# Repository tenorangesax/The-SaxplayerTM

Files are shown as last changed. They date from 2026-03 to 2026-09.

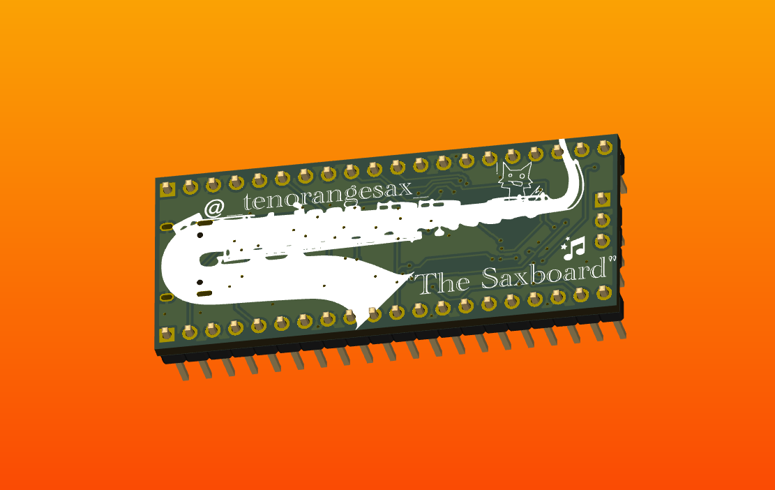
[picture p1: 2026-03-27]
Extra_Materials/Saxboard.png

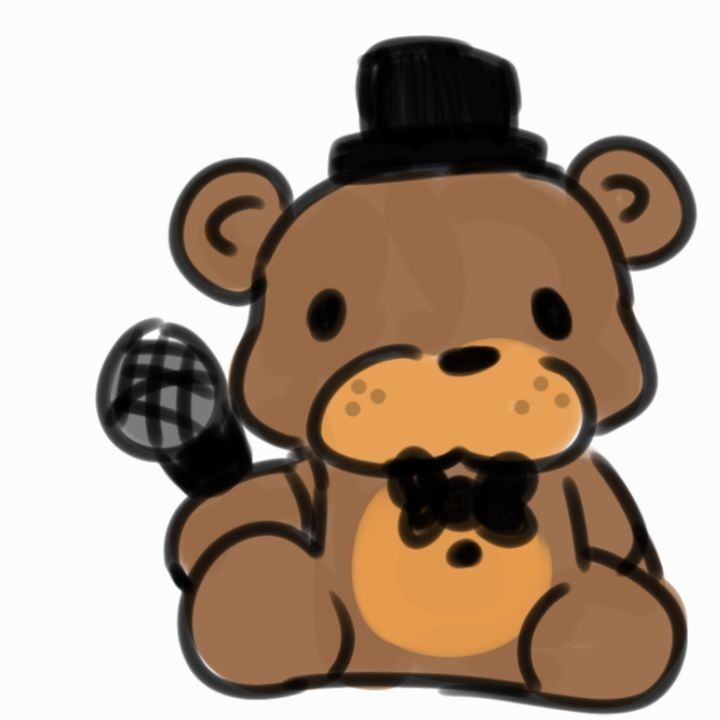
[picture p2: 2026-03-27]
Extra_Materials/_ (8).jpeg

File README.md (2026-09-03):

# The-Saxplayer™
The Saxplayer™ is a device that houses a ESP32E for the microcontroller, a OLED display to see what songs are playing, 3 MX-Style keyboard switches for navigation of songs, a rotary encoder switch for adjusting the volume and navigating menus, a micro sd card slot for storing your music, and a audio jack for headphones or output to speakers! Also has a cool case I made along with it!

**FIRMWARE GUIDE AT BOTTOM!**

**[WORKING VIDEO DEMO LINK!!!](https://youtu.be/1pTQ9vNJp9s)**

**FINAL SHOTS:**




**THE CASE:**





**3D VIEWER:**

Back_final
Front_Final

**THE SCHEMATIC:**
schematic

**PCB EDITOR:**
the components

**CASE MODELING:**
Screenshot 2026-04-18 at 4 40 20 PM
Screenshot 2026-04-18 at 4 41 53 PM
Screenshot 2026-04-18 at 4 41 45 PM
Screenshot 2026-04-18 at 4 41 21 PM

**BOM:**

| Item name | Quantity | Single price | Link to purchase | Description |
|---|---:|---:|---|---|
| Cherry MX-compatible PCB switch | 3 | $0.40 | [MechanicalKeyboards](https://mechanicalkeyboards.com/products/cherry-mx-honey-silent-45g-tactile-pcb-mount-switch) | Keyboard switch for the 3 keys |
| Micro SD card socket | 1 | $1.52 | PCBA assembled by JLCPCB | MicroSD push-push SMT socket |
| 1.3in 128x64 I2C OLED display | 1 | $5.27 | [Amazon](https://www.amazon.com/JAMHER-Display-Self-Luminous-Projects-Raspberry/dp/B0F3D2ZQZ4?th=1) | Monochrome OLED display |
| 10k resistor | 4 | $0.02 | [Amazon](https://www.amazon.com/LuminologyPro-1000-Piece-Resistor-25-Value-1%CE%A9-1M%CE%A9/dp/B0F4P352BB) | Through-hole resistor |
| 3.5mm audio jack | 1 | $1.52 | [DigiKey](https://www.digikey.com/en/products/detail/same-sky-formerly-cui-devices/SJ2-35954A-SMT-TR/6619576) | Right-angle SMT audio jack |
| 10uF capacitor | 1 | $0.10 | [Amazon](https://www.amazon.com/Rubycon-Electrolytic-Capacitor-Aluminum-Capacitors/dp/B0F8C24M5R?s=industrial&th=1) | Polarized capacitor |
| Rotary encoder with push switch | 1 | $4.90 | [Amazon](https://www.amazon.com/WWZMDiB-Encoder-Digital-Potentiometer-Arduino/dp/B0C6Q67V97?s=industrial) | Rotary input control |
| 0.1uF capacitor | 2 | $0.05 | [Amazon](https://www.amazon.com/BOJACK-Capacitor-Multilayer-Monolithic-Assortment/dp/B085RDTCCV?th=1) | Decoupling capacitor |
| 10uF capacitor | 2 | $0.10 | [Amazon](https://www.amazon.com/BOJACK-Capacitor-Multilayer-Monolithic-Assortment/dp/B085RDTCCV?th=1) | Capacitor |
| 4.7k resistor | 2 | $0.02 | [Amazon](https://www.amazon.com/LuminologyPro-1000-Piece-Resistor-25-Value-1%CE%A9-1M%CE%A9/dp/B0F4P352BB) | Pull-up / signal resistor |
| ESP32 DevKitC board | 1 | $10.00 | [Amazon](https://www.amazon.com/HiLetgo-ESP-WROOM-32-Development-Microcontroller-Integrated/dp/B0718T232Z?s=industrial) | Main controller board |

# Saxplayer™ Firmware (MicroPython)

WAV music player firmware for the Saxplayer board (ESP32-WROOM, SH1106/SSD1306 OLED, microSD, 3 MX switches, EC11 encoder, 3.5mm jack driven by the ESP32's internal DACs).

## Flashing

1. Install [esptool](https://docs.micropython.org/en/latest/esp32/tutorial/intro.html) and grab the latest ESP32 MicroPython firmware from micropython.org/download/ESP32_GENERIC/
2. Flash it (adjust the port):
   ```
   esptool.py --chip esp32 --port /dev/tty.usbserial-XXXX erase_flash
   esptool.py --chip esp32 --port /dev/tty.usbserial-XXXX write_flash -z 0x1000 ESP32_GENERIC-*.bin
   ```
3. Copy this Firmware folder's `.py` files to the board with [mpremote](https://docs.micropython.org/en/latest/reference/mpremote.html):
   ```
   mpremote cp boot.py config.py inputs.py wavplayer.py main.py :
   mpremote mkdir lib
   mpremote cp lib/sh1106.py lib/ssd1306.py :lib/
   mpremote reset
   ```

## Preparing music

Convert anything (MP3, FLAC, ...) to player readable WAV with ffmpeg, then drop it on the SD card (FAT32):

```
ffmpeg -i song.mp3 -ac 1 -ar 16000 -sample_fmt s16 song.wav
```

Mono, 16 kHz, 16-bit is prefered.
## Controls

| Input | Browser | Now playing |
|---|---|---|
| SW1 (up) | move up | previous track |
| SW3 (down) | move down | next track |
| SW2 (select) | play | play / pause |
| Encoder turn | volume | volume |
| Encoder push | rescan SD | stop, back to browser |

## Files

- `config.py` — every pin assignment and tunable, matches the KiCad netlist
- `inputs.py` — IRQ-driven buttons + quadrature encoder decoding
- `wavplayer.py` — WAV parsing and DAC playback (viper-optimized conversion)
- `main.py` — SD mount, file browser, now-playing UI
- `lib/sh1106.py`, `lib/ssd1306.py` — OLED drivers (1.3" panels are usually SH1106; switch with `OLED_DRIVER` in config.py)

## Hardware errors (check before assembling!)

The rotary encoder's common pin (C) and switch return (S2) reach GND **only through capacitors C4/C5**. Capacitors block DC, so as designed the encoder can never actually pull GPIO13/14/27 low, so turns and pushes won't register.

It would already be bridged for you by me, but if not, bridge C4 and C5 with a solder blob/0Ω resistor.

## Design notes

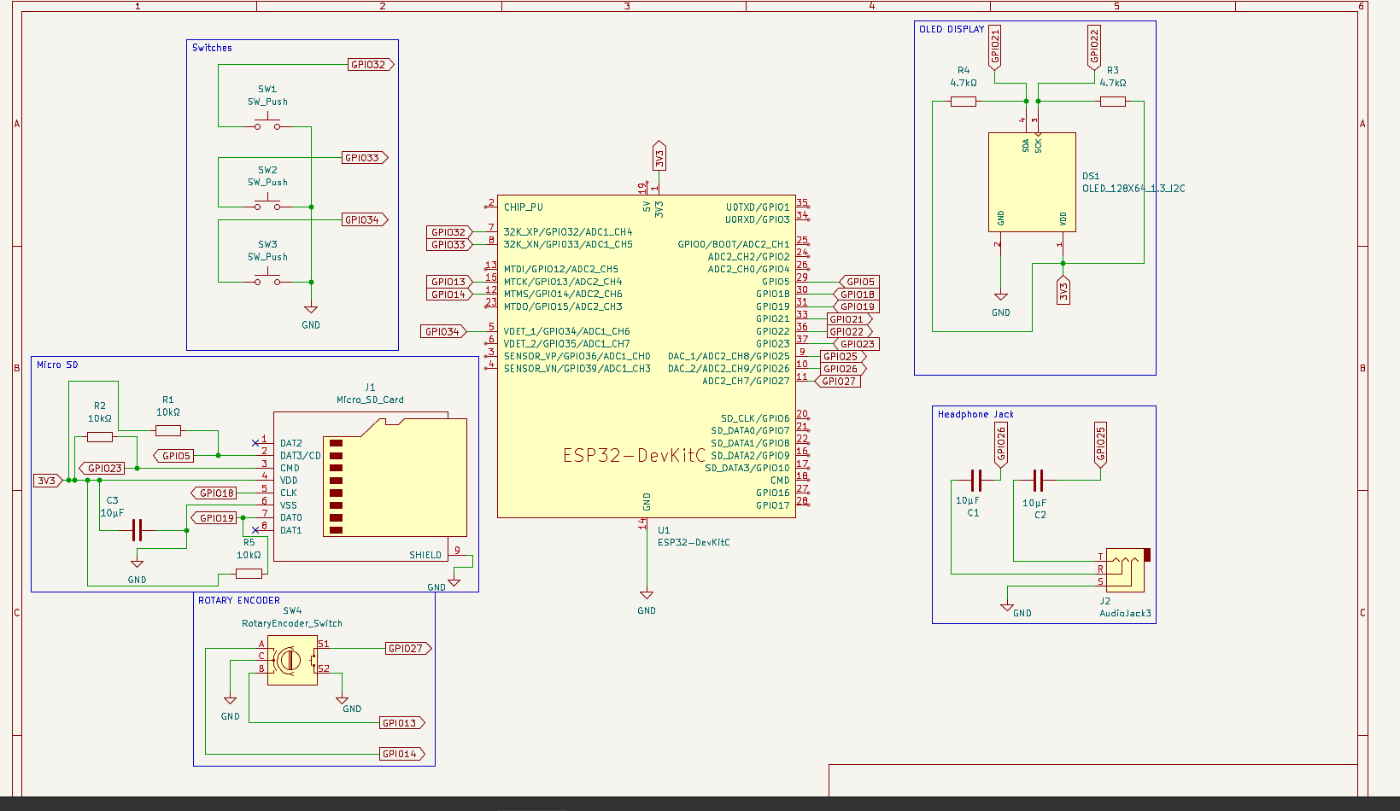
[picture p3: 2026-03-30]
PICTURES/FINAL/another schematic.png

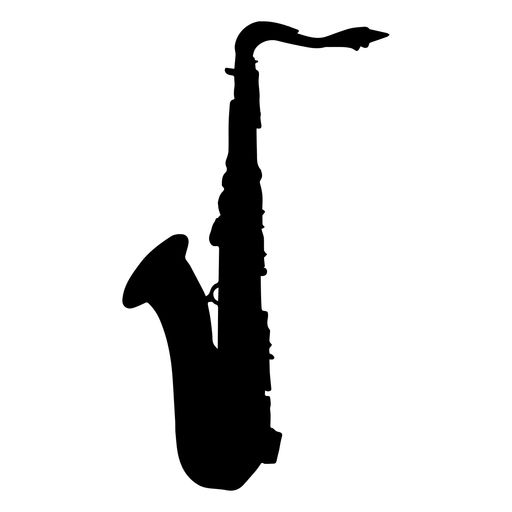
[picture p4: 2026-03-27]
Extra_Materials/Saxophone Musical Instrument Silhouette PNG & SVG Design For T-Shirts.jpeg

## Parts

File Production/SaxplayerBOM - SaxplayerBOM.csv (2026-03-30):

Id | Designator | Footprint | Quantity | Comment | Supplier and ref
1 | SW2,SW1,SW3 | SW_Cherry_MX_1.00u_PCB | 3 | SW_Push
2 | J1 | J_SD_Card-micro_socket_A | 1 | Micro_SD_Card
3 | DS1 | LCD_OLED_128X64_1.3_I2C | 1 | OLED_128X64_1.3_I2C
4 | R6,R5,R1,R2 | R_Axial_DIN0207_L6.3mm_D2.5mm_P7.62mm_Horizontal | 4 | 10kΩ
5 | J2 | Jack_3.5mm_CUI_SJ-3523-SMT_Horizontal | 1 | AudioJack3
6 | C3 | CP_Radial_D5.0mm_P2.00mm | 1 | 10µF
7 | SW4 | RotaryEncoder_Alps_EC11E-Switch_Vertical_H20mm | 1 | RotaryEncoder_Switch
8 | C5,C4 | C_Disc_D3.0mm_W1.6mm_P2.50mm | 2 | 0.1uF
9 | C2,C1 | C_Disc_D5.0mm_W2.5mm_P5.00mm | 2 | 10µF
10 | R3,R4 | R_Axial_DIN0207_L6.3mm_D2.5mm_P7.62mm_Horizontal | 2 | 4.7kΩ
11 | U1 | ESP32-DevKitC | 1 | ESP32-DevKitC

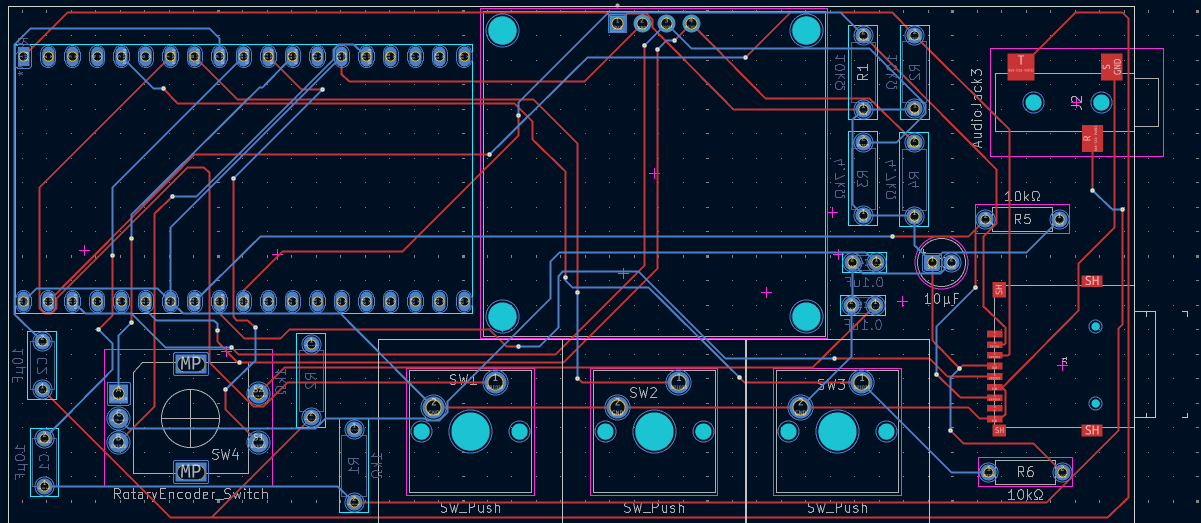
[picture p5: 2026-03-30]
PICTURES/FINAL/another component view.png

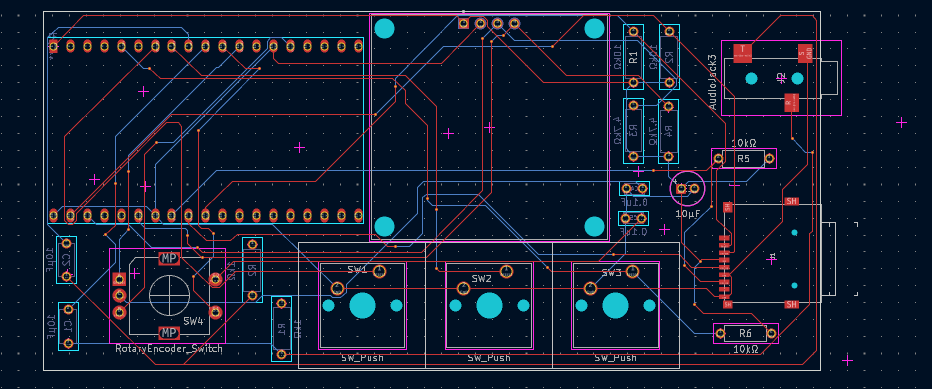
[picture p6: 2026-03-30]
PICTURES/FINAL/the components.png

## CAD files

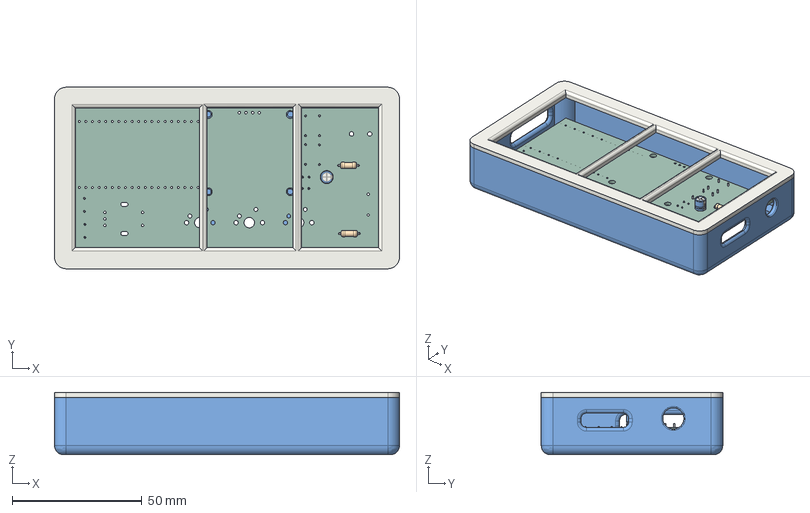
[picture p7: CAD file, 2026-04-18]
CAD/Saxplayer Case.step
132.8 x 69.9 x 24.0 mm
R_Axial_DIN0207_L6.3mm_D2.5mm_P7.62mm_Horizontal x 6
CP_Radial_D5.0mm_P2.00mm
C_Disc_D3.0mm_W1.6mm_P2.50mm x 2
C_Disc_D5.0mm_W2.5mm_P5.00mm x 2
Saxplayer_PCB

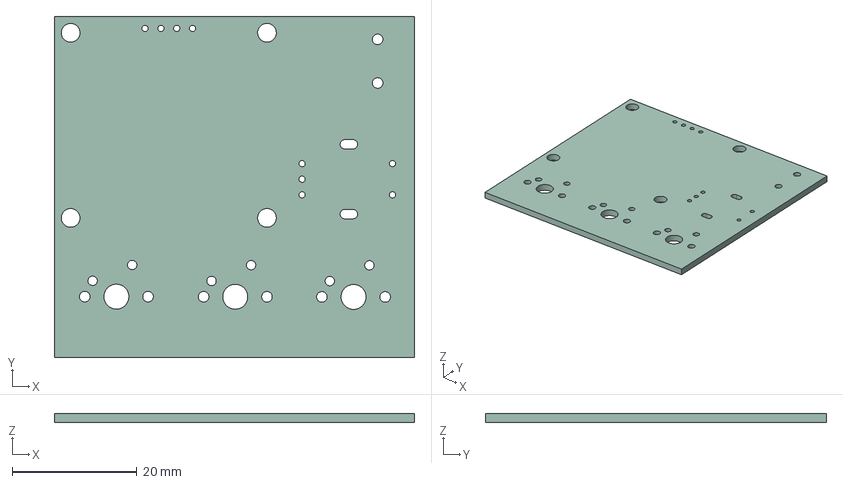
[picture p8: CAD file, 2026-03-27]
PCB/Saxplayer.step
57.8 x 54.7 x 1.51 mm

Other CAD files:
CAD/Saxplayer Case.f3d

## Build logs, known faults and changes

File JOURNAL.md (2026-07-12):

[JOURNAL (1).md](https://github.com/user-attachments/files/29402573/JOURNAL.1.md)<!--
  This journal is auto generated by Stasis.
-->

# 7/11/2026 12 PM - Final Touches and Soldering!

_Time spent: 9.3h_

All the parts finally arrived from JLCPCB, so I got started on working!
I originally had a board with my fully assembled components, but the thing was, my display wasn't working and my rotary encoder wasn't working.
The display and the ESP32 kept getting very hot whenver I plugged in the board, and the rotary encoder wasn't reading signals right, not displaying
the inputs given to it.

I had to do a lot of research and asking in slack, and the problem was eventually found. 

Apparently, on the oleds I used, the pins were GND, VCC, SCL, then SDA. The footprint I used swapped the GND and VCC, causing the oled to be totally
fried and start to heat up.

PNG image 2

PNG image

I then ordered a new ESP32 and OLED since I tried for hours trying to desolder the ESP32 to no avail. I put an atrocious amount of flux and used wick but couldn't salvage it.


The OLED I bought had the VCC and then GND so I wouldn't have to
solder any wires or put additonal stuff on my board.
61C2CYciYYL _SL1100_

I made two boards in the meantime, one with the stuff that I knew worked(the switches, headphone jack and SD card), and one with more experimental things.
On the experimental board, for the rotary encoder, I put 0 ohm resistors to act as a wire instead of the capacitors, since I researched and found out that the
capacitors could be blocking signal/not having a good enough signal to detect an input from the rotary.

When the new ESP32 and OLED arrived, I soldered it, made some test code, and everything worked!!!



I had to adjust the code a lot, since there was a lot of noise, mainly electrical, and got it to reduce a ton. The other issues were the pitch, so I had to also tweak some things
so that the sound would come out right and less garbled. I figured out that plugging this into a speaker worked best, which is perfect for Opensauce to display!

On the display, I had a setting where it would show an equalizer with the song title and artist, and the buttons were so that if you held the back/forwards button, it would accelerate in the song, like an iPod.



On the homepage, it shows all the songs, and a settings menu.



In the settings menu, I made it so that you could toggle if you wanted the equalizer or not, and if you wanted the display to sleep or not. When the display has to move less or display nothing at all, the sound quality increases because of the I2C traffic.



Lastly, I also added some keycaps from my keyboard to give more color, swabbed the flux away to be cleaner, got an SD card with songs, and did the demo!

Throughout my boards, I got better at soldering and managed to make it super clean compared to my first board for this project, which is super great!

I ditched the case, at least mostly. I had to saw off some parts since it didn't fit (and I am still learning Fusion). But I really like the designs I put on the case, so I guess
I will take it with me anyhow.





# 4/18/2026 9 PM - Made the final case

_Time spent: 2h_

I did a lot of fusion360 tutorials today so I could make the case.

I learned a lot and did a lot of researching.
I updated the pictures tab of my github and the readme to have the pictures, and made a new directory for the cad files.
Screenshot 2026-04-18 at 4.53.11 PM

Here are the finals and the in-progress views.

Saxplayer_Case_Full

Uploading Saxplayer_Case_Top.png...

Uploading Saxplayer_Case_Bottom.png...

Uploading Saxplayer_Case_Alt_View.png...

Uploading old_case.png...
shot of some workings of the case

Screenshot 2026-04-18 at 4.53.29 PM






# 3/30/2026 12 AM - JLCPCB order in cart + firmware fix + github update

_Time spent: 3.25h_

Today I put the pcb in my cart, and I had to get the sd card slot and the headphone jack assembled because it is really hard for SMD components. Everything else I'll be assembling and soldering myself. I also tweaked the firmware a bit, and updated the github.

Screenshot 2026-03-29 at 7.03.44 PM

Screenshot 2026-03-29 at 7.03.53 PM

Screenshot 2026-03-29 at 7.05.39 PM

Screenshot 2026-03-29 at 7.06.39 PM

Screenshot 2026-03-29 at 7.11.17 PM

Screenshot 2026-03-29 at 7.29.28 PM








# 3/29/2026 5 AM - Revamped everything, basically had to restart everything ground up

_Time spent: 6.716666666666667h_

Today I decided that I needed to have more ports to be able to support microsd card slot and other stuff, so I removed the seed and researched about the ESP32 Wroom, then searched for the foot + sym, adjusted the headphone jack and did a lot of learning on that, to be able to have a mostly clear sound with the capacitors and stuff. I did more research on how the sd card slot works and had to find a footprint for the symbol, then checked which pins on the ESP32 had specific functions for different things, and eventually made the schematic. I redid the design for the pcb, going for a more longer rectangle kind of look, adding the SD card and moving the headphone jack to the right side to be accessible, keeping the same 3 keys under the oled and having the ESP on the left for access and put the rotary on the top right. I used the dead space for the capacitors and resistors, wired everything up, and redid the front and back silkscreen. There was a lot to it, but I think I can raise the complexity a little for this project and have slightly advanced beginners/intermediate people be more comfortable with an ESP32 instead of just the xiao seeed esp32 since literally all other tutorials use that. I attached the new iterations and the old iterations.
Screenshot 2026-03-28 at 12.09.18 AM

Screenshot 2026-03-28 at 11.59.10 PM

Screenshot 2026-03-28 at 11.59.04 PM

Screenshot 2026-03-28 at 11.05.54 PM

Screenshot 2026-03-28 at 10.25.16 PM

Screenshot 2026-03-28 at 11.59.49 PM

Screenshot 2026-03-28 at 11.59.33 PM

Screenshot 2026-03-28 at 2.34.35 AM

Screenshot 2026-03-28 at 2.34.30 AM

Screenshot 2026-03-28 at 2.03.27 AM












# 3/27/2026 2 AM - firmware + full git finished

_Time spent: 2.75h_

I finished sorting all the files into the github today, and did all the micropython firmware for the mp3 player/streamer. I had to search a lot online how to program in this and to configure the stuff, but i think it mostly works. I might have to change the firmware if something goes wrong when i actually get the board, but for now, this is good.

attached are some previews (check the actual git for the stuff)
Screenshot 2026-03-26 at 9.24.29 PM

Screenshot 2026-03-26 at 9.24.45 PM




# 3/26/2026 4 AM - Final Touches and silkscreen

_Time spent: 3h_

I did the finishing touches to the board and did all the silkscreen stuff and finished off the errors.

here are the views:
Screenshot 2026-03-25 at 11.23.04 PM

Screenshot 2026-03-25 at 11.40.28 PM

Screenshot 2026-03-25 at 11.40.34 PM

Screenshot 2026-03-25 at 11.40.43 PM






# 3/26/2026 2 AM - PCB + SCHEMATIC REVISONS

_Time spent: 3.25h_

Today I revised and fixed the entire schematic and pcb, i was using a totally wrong symbol and footprint and needed to redo the design to be a little more better looking, since the last one was a little clunky.
I had to search a lot about the OLED displays and find one that suits this project. i then did standard testing to see if any errors popped up.

attached are some previews

Screenshot 2026-03-25 at 9.42.52 PM

Screenshot 2026-03-25 at 9.42.59 PM

Screenshot 2026-03-25 at 9.44.36 PM

Screenshot 2026-03-25 at 9.44.44 PM






# 3/19/2026 11 PM - some pcb and some schematic

_Time spent: 3.5h_

i made the schematic, troubleshooted some stuff, and made the pcb.

i think i need to get the footprint and maybe change the oled since i just realized its wrong.

and also maybe the headphone jack.

i had to do so much research on the stuff and went through a lot of troubleshooting and errors;

heres the stuff:
Screenshot 2026-03-19 at 6.29.21 PM

Screenshot 2026-03-19 at 6.29.41 PM
